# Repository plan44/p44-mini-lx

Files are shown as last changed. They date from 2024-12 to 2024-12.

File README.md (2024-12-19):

# P44-mini-lx PCB for WS28xx SmartLEDs + DMX

This is a simple KiCAD PCB design to use a Onion Omega2(+) module as a LED + DMX controller with the [P44-xx-open](https://github.com/plan44/p44-xx-open) opensource firmware.

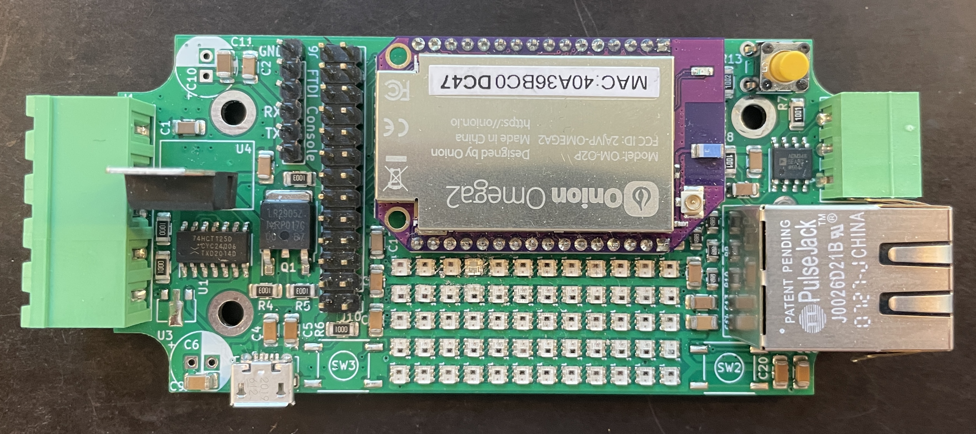
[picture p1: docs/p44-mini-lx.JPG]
p44-mini-lx WS28xx/DMX controller


## Features

- configurable for 5V powered WS2813,WS2816,SK6812 and similar as well as 12V powered WS2815.
- optional power PWM or on/off output for separate non-smart LED or powering off LED chains when idle.
- RS485 interface (not opto isolated) which can be used as DMX512 output (or to drive Swiss Railways splitflap modules, or for modbus RTU)
- Ethernet RJ45 Jack on board
- room for small 5*12 WS2816 LED array (as a test/demo, hard to solder, harder to fix soldering errors)
- two buttons
- PSU (5V or 12..24V) to 3.3V regulator (either cheap LDO for 5V PSU, or Recom switching regulator in TO220 compatible housing for PSU voltage >5V)

## Resources

- [Schematics PDF](docs/p44-mini-lx.sch.pdf)
- [Assembly views PDF](docs/p44-mini-lx.pcb.pdf)
- [iBOM - interactive bill of materials html](bom/p44mini_lx%20-%20%202024-11-26%20-%20ibom.html)

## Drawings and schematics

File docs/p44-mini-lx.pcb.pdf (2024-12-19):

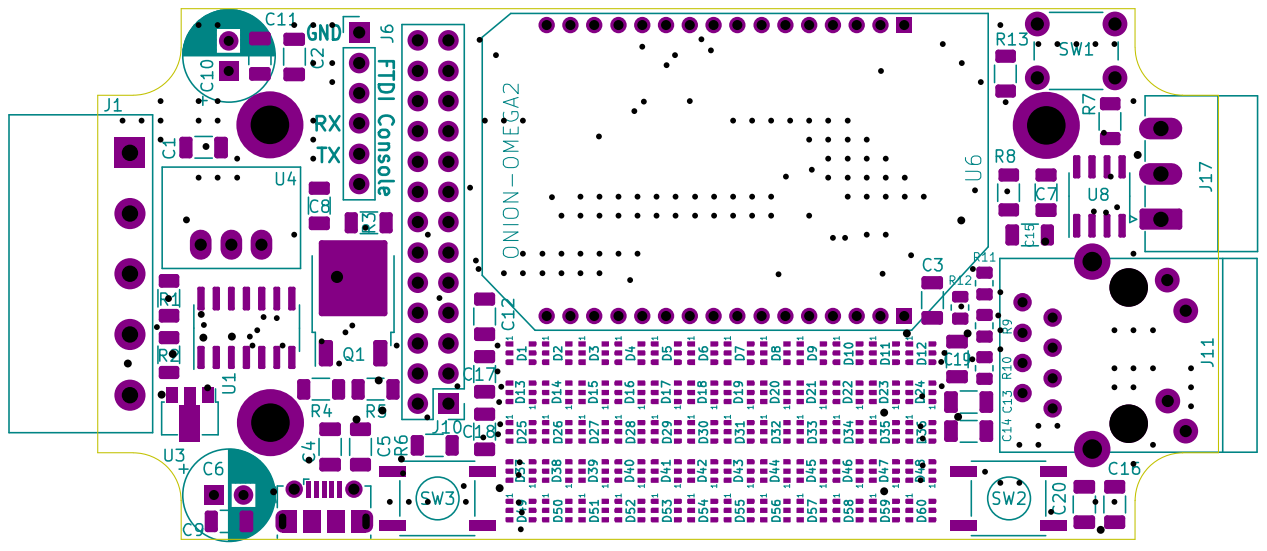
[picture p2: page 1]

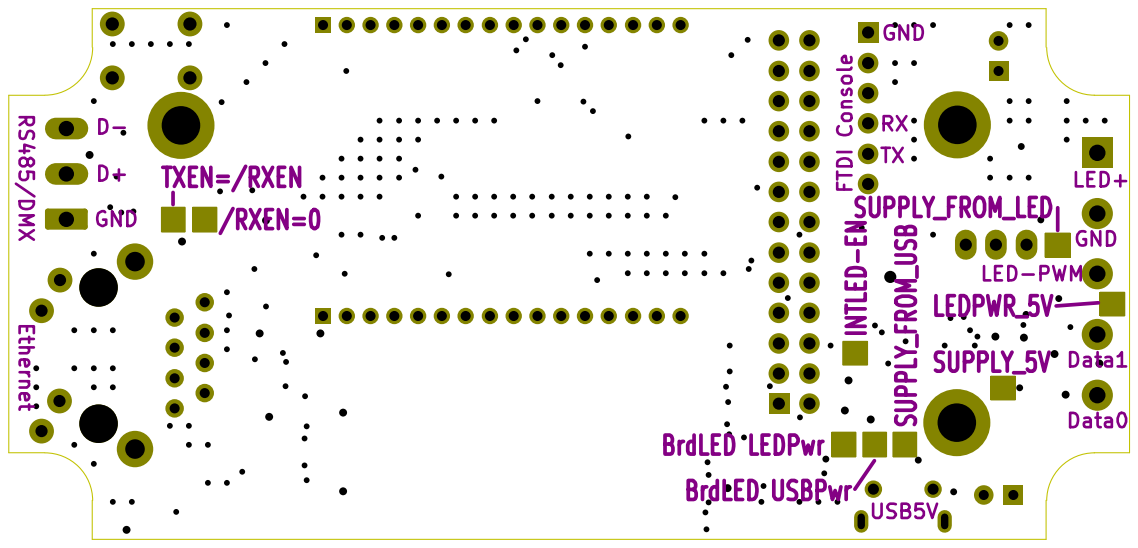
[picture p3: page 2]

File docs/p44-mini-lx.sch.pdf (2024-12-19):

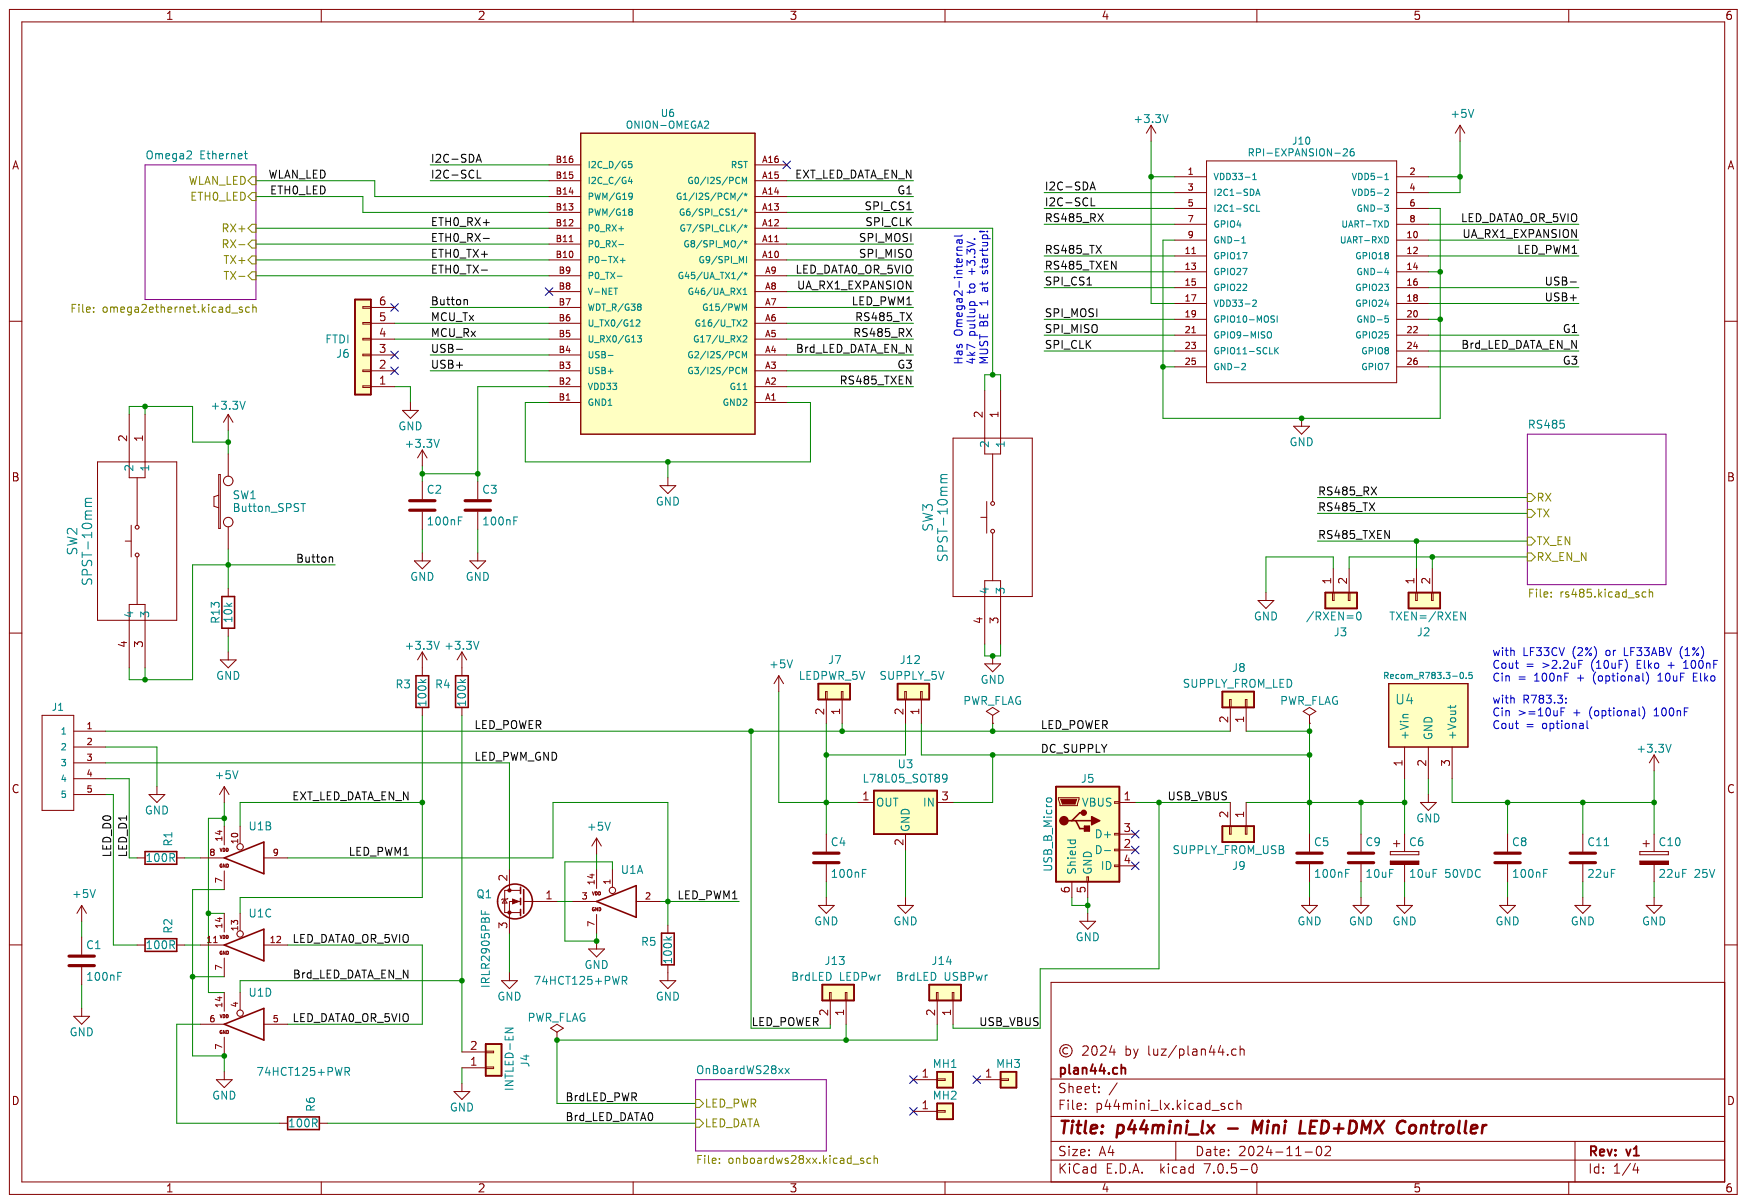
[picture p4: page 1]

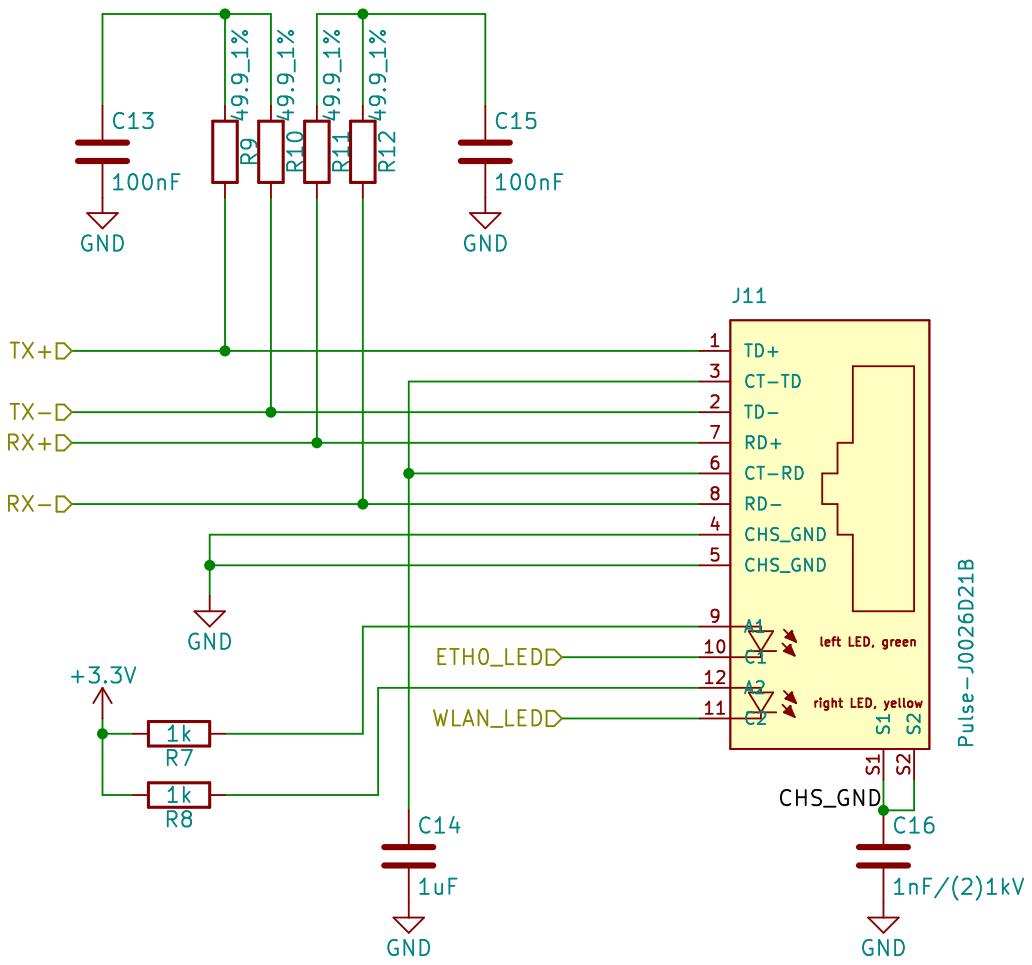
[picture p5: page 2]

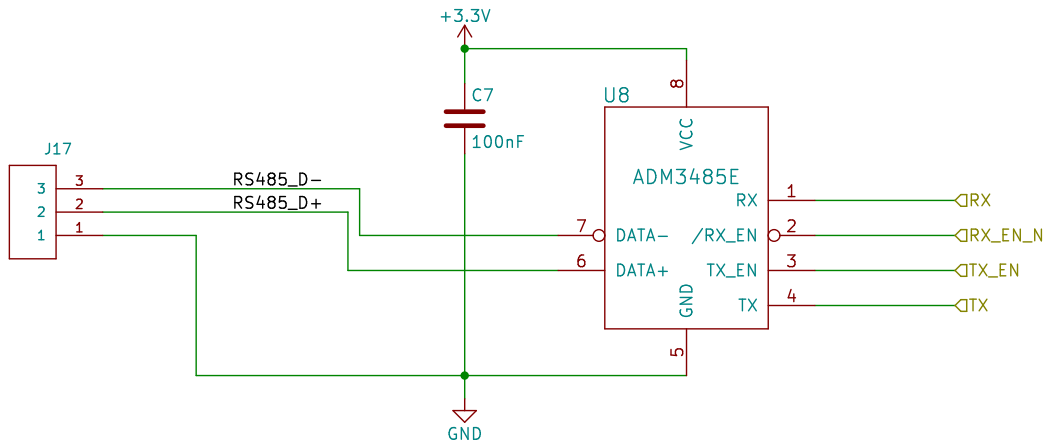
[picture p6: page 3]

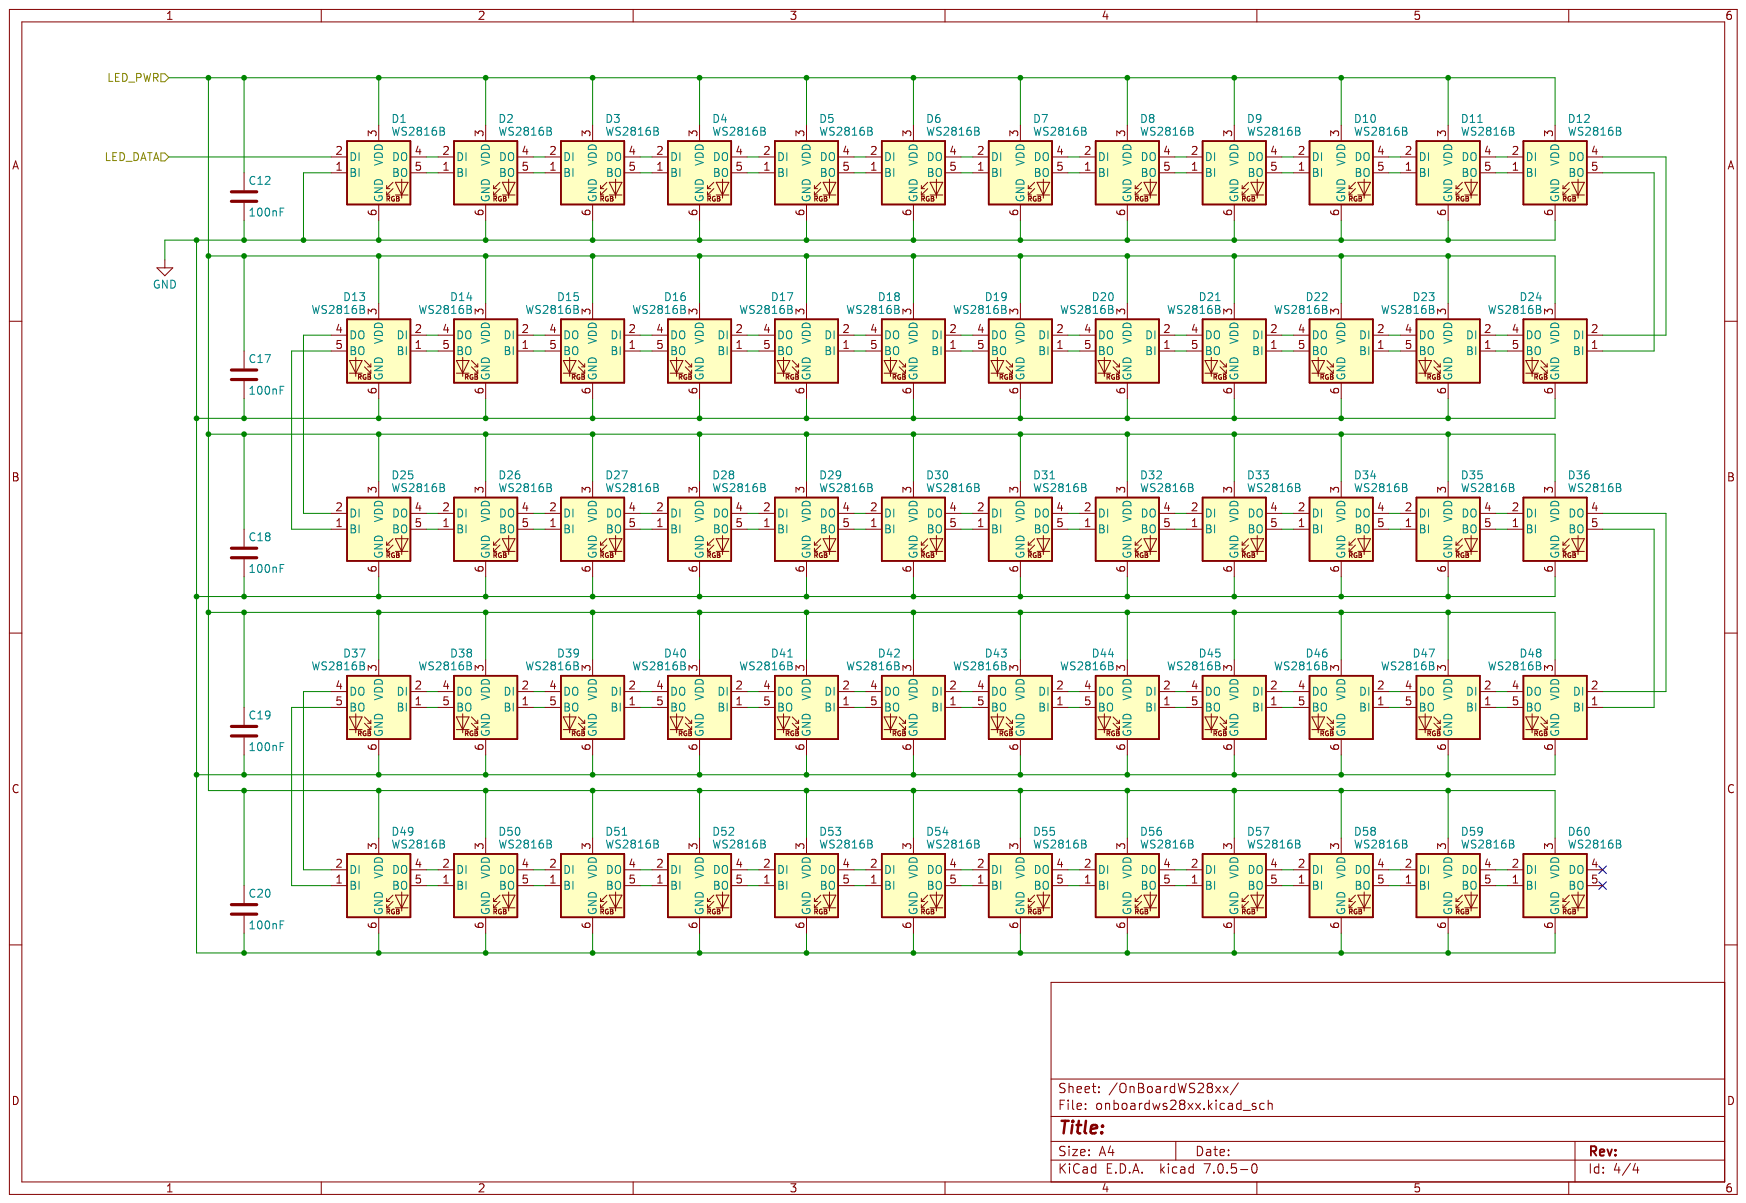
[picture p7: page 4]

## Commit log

2024-11-06 initial commit: schematics basically ok, but no DRC check, board completely WIP, OLD DESIGN SETTINGS
    [omega2ethernet.kicad_sch, onboardws28xx.kicad_sch, p44mini_lx.kicad_pcb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]
2024-11-06 schematic DRC now ok
    [omega2ethernet.kicad_sch, onboardws28xx.kicad_sch, p44mini_lx.kicad_pcb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]
2024-11-06 WIP: Power manually routed, signals mostly unrouted
    [p44mini_lx.kicad_pcb, p44mini_lx.kicad_sch]
2024-11-06 Net class for WS28xx data lines in tight LED array
    [p44mini_lx.kicad_pcb]
2024-11-06 allow 0.16mm clearance (instead of 0.2mm), still>6mil=0.01524, add 0.2mm predefined track width
2024-11-06 WIP: now WSData works with 0.2mm tracks and 0.16mm clearance
    [p44mini_lx.kicad_pcb]
2024-11-06 WIP: progress manually routed
    [freerouting.dsn, p44mini_lx.kicad_pcb, p44mini_lx.kicad_sch]
2024-11-06 NetClass "Default" clearance reduced to 0.16mm (instead of 0.2mm)
    [p44mini_lx.kicad_pcb]
2024-11-06 WIP: no DRC errors, many warnings
    [p44mini_lx.kicad_pcb]
2024-11-06 final, DRC ok except for 3x Thermal relief + courtyard/silkscreen overlaps (which we deem ok)
    [p44mini_lx.kicad_pcb, p44mini_lx.kicad_sch]
2024-11-06 Add 100R series resistor for on-board WS2816 data line
    [p44mini_lx.kicad_pcb, p44mini_lx.kicad_sch]
2024-11-06 Populate module/purpose fields for BOM, generate iBOM
    [omega2ethernet.kicad_sch, onboardws28xx.kicad_sch, p44mini_lx.kicad_pcb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]
2024-11-09 Some more minor silkscreen tweaks
    [p44mini_lx.kicad_pcb]
2024-11-09 Gerber for PCB/Stencil order
    [p44mini_lx-B_Cu.gbl, p44mini_lx-B_Mask.gbs, p44mini_lx-B_Silkscreen.gbo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]
2024-11-26 Adjustments for BOM
    [omega2ethernet.kicad_sch, p44mini_lx.kicad_pcb, p44mini_lx.kicad_sch]
2024-12-19 README + PDFs for viewing w/o KiCAD installed
